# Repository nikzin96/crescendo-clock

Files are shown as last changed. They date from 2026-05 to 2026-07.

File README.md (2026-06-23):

# Crescendo Clock - an ESP32 based alarm clock to wake up gently

<p align="center">
  <a href="#highlights">Highlights</a> •
  <a href="#how-to-use">How to use</a> •
  <a href="#main-components">Main components</a> •
  <a href="#compiling-and-customizing-the-software">Compiling and customizing SW</a> •
  <a href="#credits-and-acknowledgment">Credits</a><br>
</p>

**A self-made clock with a gentle crescendo wake up alarm**

https://user-images.githubusercontent.com/75809109/229468796-8822e73a-d802-4b9b-99c0-e9e2a0a7bf44.mp4

## Highlights
- Gentle alarm-clock with a crescendo function to wake up slowly and peacefully
- Simplified user interaction with a rotary encoder with a button. No touch display, no need for 10 different buttons
- Convenient WiFi connection via WPS. Credentials are then stored in NVS flash of the board
- Custom 3D printed case
- Integration with home assistant via MQTT messages (i.e. to create a wake up light effect)
- Light sensor to turn off display at adjust the brightness dynamically
- Written in C++ with ESP-IDF framework (no Arduino!) using Platformio + VSCode

## How to use
### Interaction elements
The user interaction with the crescendo clock takes place exclusively with the rotary encoder. This supports four possible actions:
- Left rotation
- Right rotation
- Short press / click
- Long press

Double press / click action is not supported.

### First step: connecting to WiFi
The crescendo clock sets the time automatically when it is connected to a WiFi. Manual time setting is not supported. The first time you power the clock or when the configured WiFi is not available, you will see a red wifi symbol on the right side of the screen:

https://user-images.githubusercontent.com/75809109/229468847-7dcbb47f-4164-47c6-b531-5e9feb42a694.mp4

Rotate the encoder just one click (left or right) and you will see a message "PRESS WPS". Press the WPS button of your router (or select the corresponding option of your specific router model) and wait a little bit until the WiFi connection has been established automatically. WiFi credentials are stored in NVS of ESP32 so that you will not need to repeat this step in the future. Only one credentials set can be stored: if you configure your clock for a different WiFi using the same procedure, the original WiFi credentials will no longer be present in the NVS.

### Using the crescendo clock 
This overview describes the basic usage of the crescendo clock:
| State | Rotation | Short press | Long press |
|---|:---:|:---:|:---:|
| Time | Increase brightness / activate WPS | Set alarm on/off | Enter alarm time |
| Set alarm time  | Change hour / minute of alarm | Next step | Cancel alarm setting |
| Alarm triggered | No effect | Snooze | No effect |
| Alarm snooze | Snooze cancelling sequence | Increase brightness | Snooze cancelling sequence |

Additional comments:
- If the alarm is active for triggering the alarm time is shown, otherwise it is hidden
- If the alarm is active and the remaining time until alarm triggering is less than 9 hours, this remaining "bed time" will be displayed as well
- After snoozing a triggered alarm, the alarm will be triggered again after 5 minutes if the snooze has not been cancelled
- The snooze process will continue indefinitely until it hasn't been cancelled
- The snooze cancelling sequence is like this: rotate the encoder in one direction, then long press the encoder and finally rotate the encoder in the opposite direction, waiting no longer than 3 seconds between steps. You will see one bar above the remaining time until new alarm trigger when the first step of the sequence has been successfully performed and a second bar after the second step. When the final step is performed, the remaining "snooze time" will just disappear and the alarm time will disappear as well (see the video at the beginning of this page)
- After the snooze cancelling sequence the alarm is deactivated until you activate it again manually. You need to set the alarm every single day! Remember, I designed the clock following my ideal concept of a clock and this is the way I like it.

### MQTT integration
The crescendo clock does not subscribe to any MQTT message. Instead, it sends two different messages:
- One message with the topic `wecker/wake_up` when the alarm is triggered. This will be send every time the alarm is triggered, also after the snooze phase.
- Another message with the topic `wecker/alarm_off` when the snooze cancelling sequence is complete and the alarm has been completely deactivated.

## Main components
These are the main electrical components used in this project:
- [Seeed Studio XIAO ESP32C3 board](https://wiki.seeedstudio.com/XIAO_ESP32C3_Getting_Started/)
- [Rotary encoder with board](https://www.ebay.de/itm/173657244984) OR [KY-040 rotary encoder](https://eckstein-shop.de/QITAPotentiometerDrehreglerKY-040RotaryEncoderModulforArduino)
- [2.4 inch display with ILI9341 driver](https://www.waveshare.com/2.4inch-lcd-module.htm)
- [DFRobot's DFPlayer Mini](https://www.dfrobot.com/product-1121.html)
- [Light sensor](https://www.adafruit.com/product/2748)
- [Mini-speaker](https://www.ebay.de/itm/313914312809) OR [Alternative speaker](https://www.roboter-bausatz.de/p/mini-lautsprecher-40x20mm-8-ohm-2w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)

See the [detailed description](hardware/README.md) in the hardware folder for more information about schematics, PCB, 3D printed case, detailed assembly instructions and other design considerations.

## Compiling and customizing the software
Basic knowledge about platformio, ESP-IDF development and ESP32 boards is required. This project has been tested only under a Linux environment. In order to compile this project you will need:
- Your populated PCB board with the ESP32C3 board connected to the PC via USB
- Visual Studio Code with platformio extension installed. The versions for the espressif32 platform and the LovyanGFX library in the file [platformio.ini](platformio.ini) have been set to a fixed value to avoid code breaks (which has happened several times during development).

Just build and upload the code! If you upload to code to the board with no hardware connected to it (display, encoder, etc.) you should at least be able to see some basic debug messages via Serial Monitor related to the failed WiFi connection.

### Waking melodies and other settings
In this repository there is not any audio file for the waking melody. In the [DFPlyer mini wiki](https://wiki.dfrobot.com/DFPlayer_Mini_SKU_DFR0299) you will find instructions on how to create your own files (see chapter ["Copy your mp3 into you micro SD card"](https://wiki.dfrobot.com/DFPlayer_Mini_SKU_DFR0299#target_6)). I have a folder called `mp3` in the SD-card and inside it a single file called `0001.mp3`. You can add further files and change the value of `melody_nr` in the `settings` struct in [src/clock_machine.hpp](src/clock_machine.hpp) and add the corresponding mp3 file. In case you want a confirmation sound when you activate the alarm, then set the settings variable `alarm_set_confirmation_sound` to true and make sure a (short) `0101.mp3` file exists. This does not work really well, as the DFPlayer doesn't seem to like short audio files, and I will most likely remove this feature in a near future.

Furthermore, you can change also the snooze time (default = 5 minutes) and the "crescendo speed" in the same `settings` structure. These are fixed values and cannot be changed after compilation.

## Credits and acknowledgment
For this project I have used the inspiration and code from many other projects and sources: 
- I looked up and partly copied some code from the official esp-idf examples contained in https://github.com/espressif/esp-idf/tree/master/examples (mainly those related to SNTP, WPS, MQTT and Wifi functions)
- For the rotary encoder I used some code from https://github.com/LennartHennigs/ESPRotary as well as from https://github.com/craftmetrics/esp32-button. The code from https://github.com/DavidAntliff/esp32-rotary-encoder was also a good source of inspiration
- For the finite state machine implementation I borrowed the ideas from https://www.aleksandrhovhannisyan.com/blog/finite-state-machine-fsm-tutorial-implementing-an-fsm-in-c/ as well as from https://stackoverflow.com/questions/14676709/c-code-for-state-machine
- For the DFPlayer module used this datasheet to look up the specifications https://cdn.shopify.com/s/files/1/1509/1638/files/MP3_Player_Modul_Datenblatt.pdf?10537896017176417241. I also found some undocumented functions in the library implementation in https://github.com/DFRobot/DFRobotDFPlayerMini
- [Adafruit](https://www.adafruit.com/) for the many resources I used for the creation of custom fonts and symbols (see a [more detailed description](fonts/README.md) in the resources folder) as well as for the great inspiration from their [PyPortal Alarm Clock](https://learn.adafruit.com/pyportal-alarm-clock), out of which I created a very first concept of this kind of crescendo clock. 

## License
Copyright (c) 2023 javiser
`crescendo-clock` is distributed under the terms of the MIT License.

See the [LICENSE](LICENSE) for license details.

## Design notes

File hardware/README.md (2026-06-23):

# Hardware

<p align="center">
  <a href="#schematics-and-pcb-design">Highlights</a> •
  <a href="#board-assembly">Board assembly</a> •
  <a href="#3d-printed-case">3D printed case</a> •
  <a href="#final-assembly">Final assembly</a> •
  <a href="#modifications">Modifications</a><br>
</p>

## Schematics and PCB design
<p float="left">
    
    
    
</p>

A couple of mentions to design considerations:

- The capacitors were used in a previous design to add some debouncing. In the current [rotary encoder](https://www.ebay.de/itm/173657244984) used, these capacitors are already include and are not soldered anymore
- With the exception of some SPI pins for the [display](https://www.waveshare.com/2.4inch-lcd-module.htm) and the fact that the light sensor needs an analog input, which pins to use on the ESP32 board should is actually a very free decision
- The design was made using EasyEDA and the [created GERBER files](PCB/Gerber_PCB_Crescendo_Clock_Board_rev2.0.zip) and the board manufactured by [JLCPCB](https://jlcpcb.com). This is the result:



## Board assembly

### Display connector removal
The big connector on the rear side of the display is not needed and needs to be removed in order to build the board properly. Just cut the the pins with some pliers and then you can slide out the connector:
<p float="left">
    
    
</p>

### Soldering all together
1. Solder the 1x8 pin male header on the display and 2 additional 1x1 ones as support. You can use the still empty PCB board as a holder:
<p float="left">
    
    
</p>

2. Solder a 1x3 90° pin male header on the [light sensor breakout board](https://www.adafruit.com/product/2748). Pay attention to the orientation!
<p float="left">
    
</p>

3. Solder all components to the PCB board and trim the excess length of the pins to make room for the display board
<p float="left">
    
    
</p>

4. Solder the display on the other side of the board. 
<p float="left">
    
    
</p>

5. Prepare a connection cable with 5 pins for the connection between the board and the rotary encoder breakout. Again, I used dupont connectors for this:



6. If necessary, change the connector of the mini-speaker. I used dupont connectors for this:
   
<p float="left">
    
    
    
</p>

7. After that it would be a good time to do a sanity check and connect everything together, flash the SW into the board and check whether everything is working as expected:


## 3D printed case
STL files for the [case](3D/case.stl), the [rear cover](3D/rear_cover.stl) and the [knurled rotary botton](3D/knurled_button.stl) are available. If you have used the [KY-040 rotary encoder](https://eckstein-shop.de/QITAPotentiometerDrehreglerKY-040RotaryEncoderModulforArduino) print the [knurled rotary botton new](3D/knurled_button_new.step) and if you got the [alternative speaker](https://www.roboter-bausatz.de/p/mini-lautsprecher-40x20mm-8-ohm-2w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) print the [rear cover new](3D/rear_cover_new.step):
<p float="left">
    
    
    
</p>
I printed these with PLA using an Ender 3 v2. Pay attention to the orientation when slicing: the clock front side, the outside face of the rear cover as well as the top face of the button should be your first layer. You may use supports for the big case, I didn't use any and it went ok.



You can find the original Fusion 360 files in the [3D folder](3D) as well.

## Final assembly

1. Put an SD card with the necessary audio files. See <a href="../#waking-melodies-and-other-settings">Waking melodies and other settings chapter</a> of the main README for more instructions.
2. Slide in the finished board and screw it into the case using 4 M2.5x8 screws



3. Attach the ESP32 antenna on one side of the case and connect it to the board



4. Connect the cables to the rotary encoder and slide it into its place. Put the washer and hex nut and tighten it. Make sure it is perpendicular. Insert the button into the shaft



5. Attach the speaker on the rear cover. Pay attention to the orientation, since the rear cover has an upper and a lower part and you want the cables coming out of the lower part. It should be a tight fit into the pins, otherwise use some strong glue to make sure it stays attached. In case of the [alternative speaker](https://www.roboter-bausatz.de/p/mini-lautsprecher-40x20mm-8-ohm-2w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) use short M2 screws and nuts to secure it to the rear cover (see right picure).

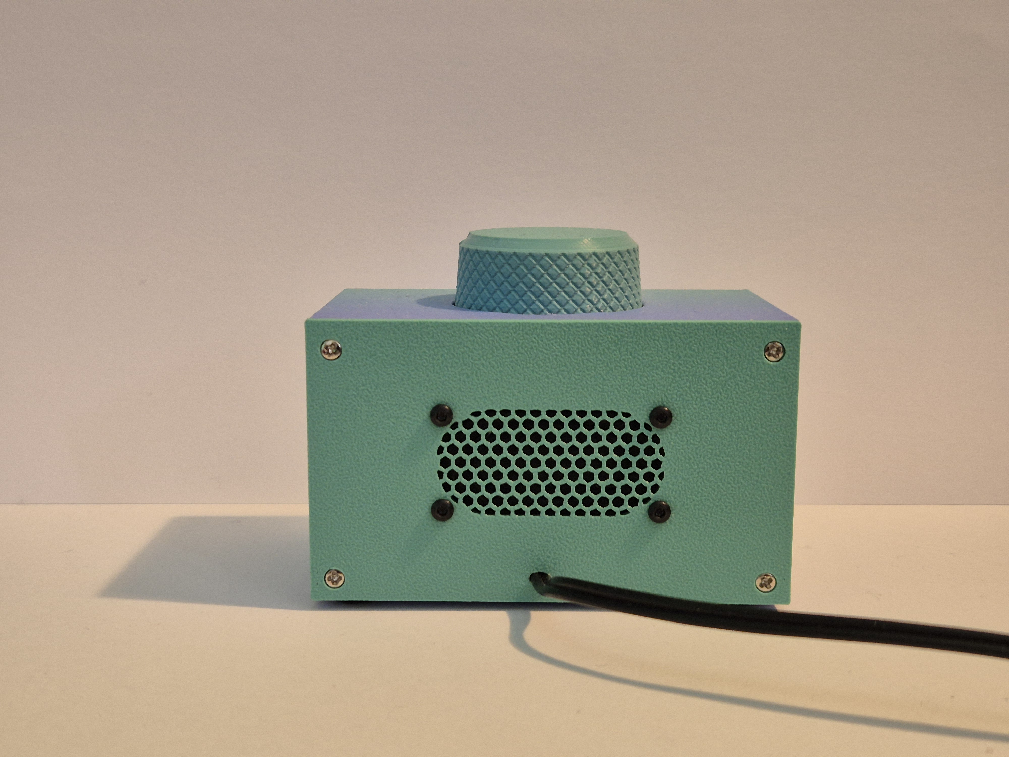
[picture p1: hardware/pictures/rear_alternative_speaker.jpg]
 

6. Connect everything together sure everything is connected  



7. Close the cover using 4 M2x4 screws

## Modifications
The components used are just what I could get my hands on or what made sense to me. Here some considerations:

- It should be possible to use any other ESP32 board. The previous version used the [ESP-C3-32S-Kit ESP32 WiFi+Bluetooth Development Board](https://www.waveshare.com/esp-c3-32s-kit.htm). You just need to make sure that you have at least 11 pins available. The pin assignments defined in [clock_common.hpp](src/clock_common.hpp) will most likely need an adjustment. If you take a variant different from the ESP32C3 you might require more extensive changes as well
- Other LCD displays could work as well, specially if the same ILI9341 driver is used, but maybe other settings are required. Since the used library LovyanGFX supports a lot of different displays, changing to another display is just a matter of adjusting the configuration and, if the resolution changes, the layout (font sizes, symbol and text positions)
- In general any other component like the rotary encoder, speaker or the light sensor should be exchangeable with no or little effort

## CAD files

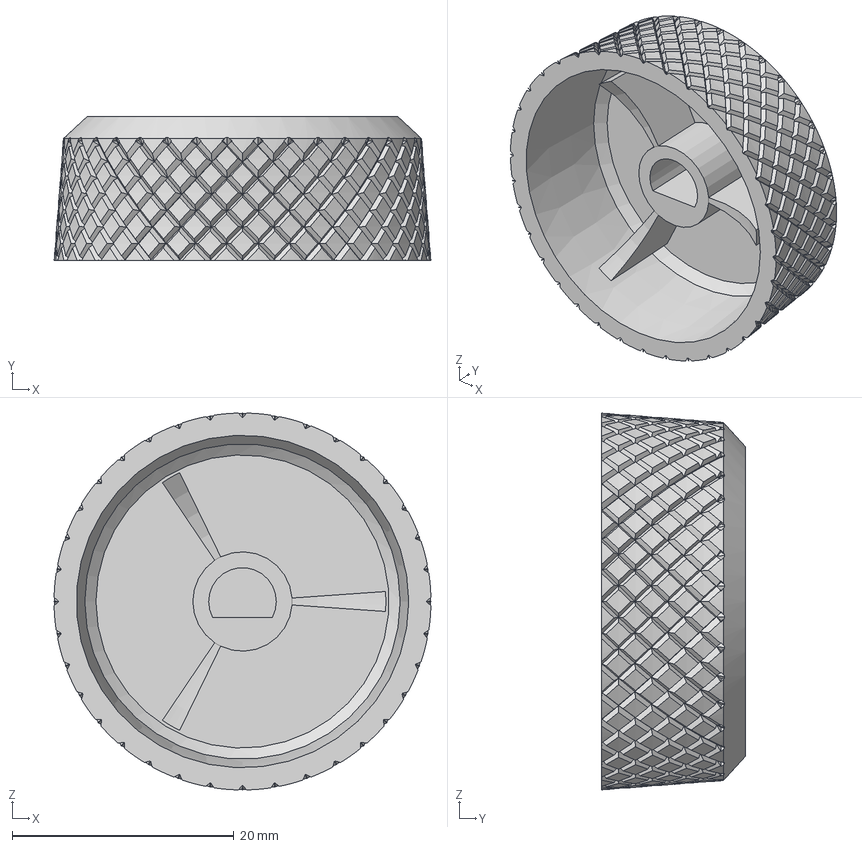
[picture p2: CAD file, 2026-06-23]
hardware/3D/knurled_button_new.step
34.0 x 13.0 x 34.0 mm

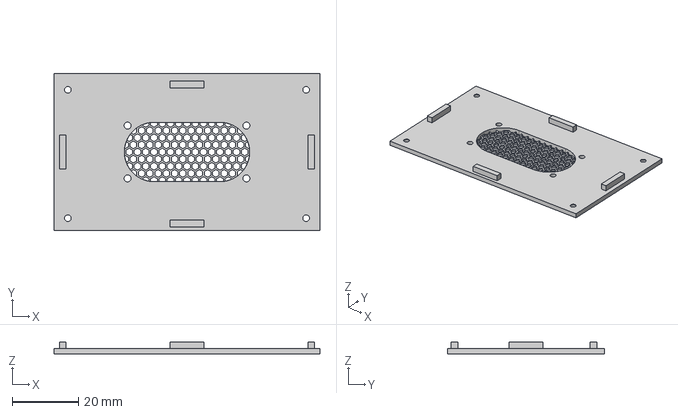
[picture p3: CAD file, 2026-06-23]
hardware/3D/rear_cover_new.step
80.6 x 47.7 x 3.60 mm

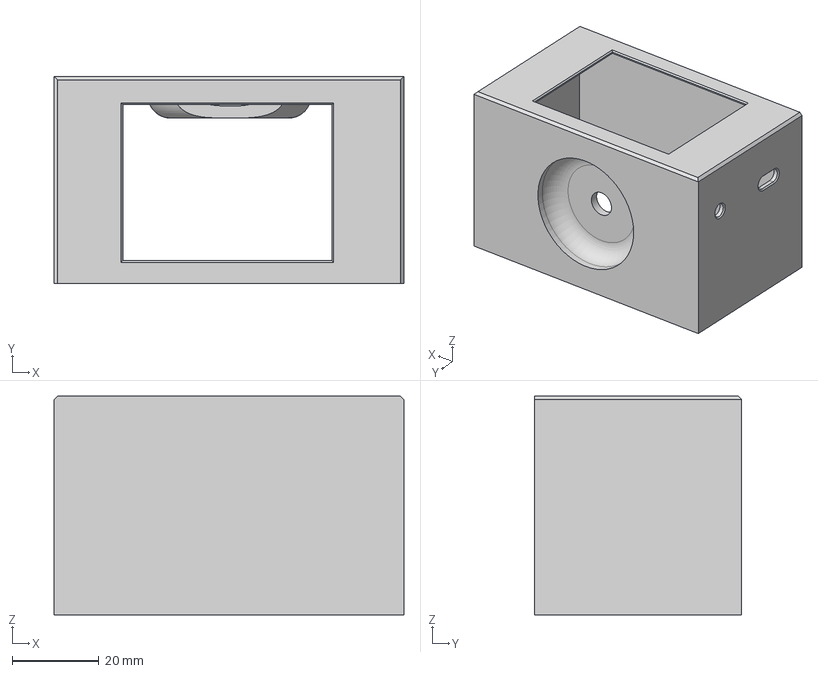
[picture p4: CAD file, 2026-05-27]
hardware/3D/case.step
80.6 x 47.7 x 50.4 mm

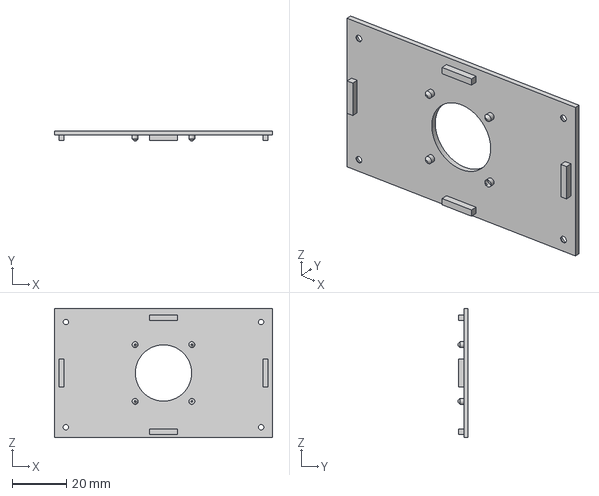
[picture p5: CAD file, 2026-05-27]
hardware/3D/rear_cover.step
80.6 x 3.80 x 47.7 mm

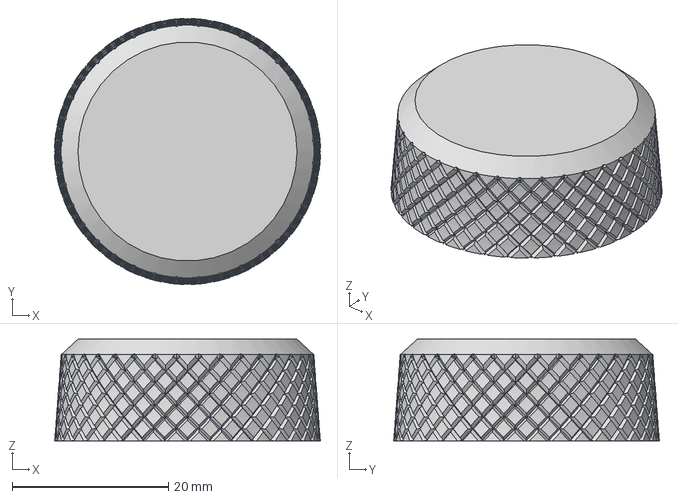
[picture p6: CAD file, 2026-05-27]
hardware/3D/knurled_button.step
34.0 x 34.0 x 13.0 mm

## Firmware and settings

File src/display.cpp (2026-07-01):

#include "freertos/FreeRTOS.h"
#include "freertos/event_groups.h"
#include "driver/ledc.h"
#include <display.hpp>
#include <Antonio_SemiBold75pt7b.h>
#include <Antonio_Regular26pt7b.h>
#include <Antonio_Light16pt7b.h>

void Display::monitorBrightnessTask(void *pvParameter) {
    Display *pThis = (Display *)pvParameter;
    bool event;
    while (1) {
        xQueueReceive(pThis->queue, &event, 1000 / portTICK_PERIOD_MS);
        pThis->controlBrightness();
    }
}

void Display::init(void) {
    lcd.init();
    lcd.setRotation(0);
    lcd.setColorDepth(16);

    // ADC1 config for light sensor
    adc_oneshot_unit_init_cfg_t init_config1 = {
        .unit_id = ADC_UNIT_1,
        .clk_src = ADC_DIGI_CLK_SRC_APB,
        .ulp_mode = ADC_ULP_MODE_DISABLE,
    };
    ESP_ERROR_CHECK(adc_oneshot_new_unit(&init_config1, &adc1_handle));    
    adc_oneshot_chan_cfg_t config = {
        .atten = LIGHT_ADC_ATTEN,
        .bitwidth = ADC_BITWIDTH_12,
    };
    ESP_ERROR_CHECK(adc_oneshot_config_channel(adc1_handle, LIGHT_ADC_CHANNEL, &config));

    xTaskCreate(this->monitorBrightnessTask, "monitor_brightness_task", 2048, this, 1, NULL);
    queue = xQueueCreate(1, sizeof(bool));
}

void Display::updateContent(display_element_t element, void *value, display_action_t action) {
    switch (element) {
        case D_E_TIME:
            char time_buf[8];
            snprintf(time_buf, sizeof(time_buf), "%02d:%02d", static_cast<clock_time_t *>(value)->hour, static_cast<clock_time_t *>(value)->minute);
            lcd.setTextDatum(top_center);

            switch (action) {
                case D_A_ON:
                    lcd.setTextColor(TFT_WHITE, TFT_BLACK);
                    break;
                default:
                    break;
            }
            lcd.drawString(time_buf, (lcd.width() / 2) + 5, 10, &Antonio_SemiBold75pt7b);
            break;

        case D_E_ALARM_TIME:
            char alarm_buf[8];
            snprintf(alarm_buf, sizeof(alarm_buf), "%02d:%02d", static_cast<clock_time_t *>(value)->hour, static_cast<clock_time_t *>(value)->minute);
            char alarm_symbol_buf[2];
            snprintf(alarm_symbol_buf, sizeof(alarm_symbol_buf), DISPLAY_SYMBOL_ALARM_ON);
            lcd.setTextColor(TFT_WHITE, TFT_BLACK);  // Normal case
			lcd.setTextDatum(middle_center);
            switch (action) {
                case D_A_OFF:
                    lcd.setTextColor(TFT_DARKGRAY, TFT_BLACK);
                    snprintf(alarm_symbol_buf, sizeof(alarm_symbol_buf), DISPLAY_SYMBOL_ALARM_OFF);
                    snprintf(alarm_buf, sizeof(alarm_buf), "     ");
                    break;
                case D_A_HIDE_HOURS:
                    alarm_buf[0] = alarm_buf[1] = ' ';
                    break;
                case D_A_HIDE_MINUTES:
                    alarm_buf[3] = alarm_buf[4] = ' ';
                    break;
                default:
                    break;
            }
            lcd.drawString(alarm_symbol_buf, 35, 205, &Antonio_Regular26pt7b);
            lcd.drawString(alarm_buf, 100, 200, &Antonio_Regular26pt7b);
            break;

        case D_E_BED_TIME:
            char bed_time_buf[8];
            snprintf(bed_time_buf, sizeof(bed_time_buf), "%01d:%02d", static_cast<clock_time_t *>(value)->hour, static_cast<clock_time_t *>(value)->minute);
            char bed_time_symbol_buf[3];
            snprintf(bed_time_symbol_buf, sizeof(bed_time_symbol_buf), DISPLAY_SYMBOL_BED);
            lcd.setTextColor(TFT_LIGHTGRAY, TFT_BLACK);  // Normal case
			lcd.setTextDatum(middle_center);
            // We show the remaining bed time only when less than 9 hours
            if (static_cast<clock_time_t *>(value)->hour >= 9)
                action = D_A_OFF;

            switch (action) {
                case D_A_OFF:
                    snprintf(bed_time_buf, sizeof(bed_time_buf), "    ");
                    snprintf(bed_time_symbol_buf, sizeof(bed_time_symbol_buf), "  ");
                    break;
                default:
                    break;
            }
            lcd.drawString(bed_time_symbol_buf, 180, 205, &Antonio_Regular26pt7b);
            lcd.drawString(bed_time_buf, 235, 200, &Antonio_Regular26pt7b);
            break;

        case D_E_SNOOZE_TIME:
            char snooze_buf[8];
            lcd.setTextDatum(middle_center);
            lcd.setTextColor(TFT_ORANGE, TFT_BLACK);
            switch (action) {
                case D_A_OFF:
                    snprintf(snooze_buf, sizeof(snooze_buf), "     ");
                    lcd.drawString("  ", 175, 205, &Antonio_Regular26pt7b);
                    break;
                case D_A_ON:
                    uint8_t minutes;
                    uint8_t seconds;
                    uint16_t remaining_seconds;
                    remaining_seconds = *(static_cast<uint16_t *>(value));
                    minutes = remaining_seconds / 60;
                    seconds = remaining_seconds % 60;
                    snprintf(snooze_buf, sizeof(snooze_buf), "%01d:%02d", minutes, seconds);
                    lcd.drawString(DISPLAY_SYMBOL_SNOOZE, 175, 205, &Antonio_Regular26pt7b);
                    break;
                default:
                    break;
            }
            lcd.drawString(snooze_buf, 230, 200, &Antonio_Regular26pt7b);
            break;

        default:
            break;
    }
}
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

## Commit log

2026-05-21 fix: use bounded strlcpy/snprintf in display.cpp
    Unsafe C buffer function used without size checking
    Addresses utils.custom.buffer-overflow-strcpy
    [display.cpp]
2026-05-26 add case as step
    [case.step, knureld_button.step, rear_cover.step]
2026-05-27 fix typo
    [knurled_button.step]
2026-05-29 Use latest version of LovyanGFX library, fix warnings
    [display.cpp]
2026-05-29 Fix error from last commit
    [display.cpp]
2026-06-22 add alternative rear and knob
    [knurled_button_new.step, rear_cover_new.step]
